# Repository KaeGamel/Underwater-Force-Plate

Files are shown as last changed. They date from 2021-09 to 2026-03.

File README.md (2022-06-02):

# Kaelyn-Gamel
Underwater Force Plate 

Hello all! 

Welcome to the DIY Underwater/Terrestrial Force plate! 

In order to create your own force plate we will be using different platforms and integrating them to gather small forces terrestrially or underwater(can detect .5grams)!

I would start with the files parts and programs needed. I also have attached a word doc that allows you to click on the links for most of the parts to purchase.

Fusion 360 to design the force sensors, Formlab to 3D print.

Matlab to gather data from a NIDAQ that gathers an anolog input from an INA 125P amplifier and Load cell.

EAGLE CAD to generate our circuit (if you want to edit and personalize to your likings)

Most importantly the checklist needed to integrate everything!

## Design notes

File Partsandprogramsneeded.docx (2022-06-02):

Welcome! If you are looking to make your own custom force plate for terrestrial or aquatic locomotion here is a quick setup overview.

Overview:

1) Parts needed
2) Programs needed

Parts needed

Electronics:

Custom circuit boards

INA 125P

Rechargeable 9V batteries

Battery links

Resistors 10- 1,000 ohm

Trim pots 1M-2M

Strain Gauges

Screw Terminals

Multimeter

Heat shrink 3-5mm

Nidaq USB-6002

3D printed parts

STL file from GitHub

Access to Form lab2/3 , Isopropyl, UV cure

Resin tough 2000

Filers and sandpaper

MISC

FP substrate

Aquarium Silicone

Small screwdriver

80-20 T-slot beams

80-20 screws

Programs needed

Part editing and printing

Fusion 360- to edit load cell thicknes

Preform- to print out 3D parts with formlab

EAGLE CAD- edit circuit board

Gather Data

Signal analyzer -in matlab

NIDAQmx tool box – in matlab

National instruments Package manager – National instruments (NI)

Nidaq-mx – using NI package manager

Image processing toolbox- For calibraitons getpts function- Matlab

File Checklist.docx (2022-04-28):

Welcome! If you are looking to make your own custom force plate for terrestrial or aquatic locomotion here is a Checklist and locations of purchase.

Overview:

1) Parts needed
2) Programs needed

Parts needed

Electronics:

Custom circuit boards

INA 125P

Rechargeable 9V batteries

Battery links

Resistors 10- 1,000 ohm

Trim pots 1M-2M

Strain Gauges

Screw Terminals

Multimeter

Heat shrink 3-5mm

Nidaq USB-6002

3D printed parts

STL/f3z file from GitHub

Access to Form lab2/3, Isopropyl, UV cure

Resin tough 2000

Filers and sandpaper

MISC

FP substrate

Aquarium Silicone

Small screwdriver

80-20 T-slot beams

80-20 screws

Programs needed

Part editing and printing

Fusion 360- to edit load cell thicknes

Preform- to print out 3D parts with formlab

EAGLE CAD- edit circuit board

Gather Data

Signal analyzer -in matlab

NIDAQmx tool box – in matlab

National instruments Package manager – National instruments (NI)

Nidaq-mx – using NI package manager

Links for Parts and Programs

Electronics:

Using the eagle files on the github account, you can avoid many headaches by getting PC boards made for you. We ordered from

PCB Prototype & PCB Fabrication Manufacturer - JLCPCB (https://jlcpcb.com/)

Amplifier INA 125P

INA125P Texas Instruments | Integrated Circuits (ICs) | DigiKey (https://www.digikey.com/en/products/detail/texas-instruments/INA125P/254670)

Rechargeable 9V batteries:

Amazon.com: EBL 4 Bay 9V Lithium ion Battery Charger with 4 Packs 600mAh 9V Li-ion Rechargeable Batteries : Electronics (https://www.amazon.com/EBL-Lithium-Battery-Rechargeable-Batteries/dp/B078HP76PG)

Battery links:

Amazon.com: 9 V Battery Clip Connector, I-Type 9 Volt Battery Clip, 9V Battery Buckle Connector Hard Buckle Plastic Housing and Black Red Wires Leads Iength 5.9 inches (I Type Hard Shell 8PCS) : Electronics (https://www.amazon.com/Battery-Connector-I-Type-Plastic-Housing/dp/B07TRKYZCH)

Resistors:

ELEGOO 17 Values 1% Resistor Kit Assortment, 0 Ohm-1M Ohm (Pack of 525) RoHS Compliant: Amazon.com: Industrial & Scientific (https://www.amazon.com/Elegoo-Values-Resistor-Assortment-Compliant/dp/B072BL2VX1)

Trim pots 1M/2M:

Amazon.com: 150 Pcs 15 Value 100 ohm- 2M ohm Trimpot Variable Resistor 6mm Potentiometer Assortment Kit : Industrial & Scientific (https://www.amazon.com/Trimpot-Variable-Resistor-Potentiometer-Assortment/dp/B071WW6VN8)

Strain gauges 120 or 350 ohm:

https://www.omega.com/en-us/force-strain-measurement/strain-gauges/linear-strain-gauges/kfh-linear/p/KFH-3-350-C1-11L1M2R

Screw Terminals:

KeeYees 60pcs 5mm Pitch 2 Pin & 3 Pin PCB Mount Screw Terminal Block Connector for Arduino (50 x 2 Pin, 10 x 3 Pin): Amazon.com: Industrial & Scientific (https://www.amazon.com/KeeYees-60pcs-Terminal-Connector-Arduino/dp/B07H5G7GC6)

Multimeter:

AstroAI Multimeter 2000 Counts Digital Multimeter with DC AC Voltmeter and Ohm Volt Amp Tester ; Measures Voltage, Current, Resistance; Tests Live Wire, Continuity - - Amazon.com (https://www.amazon.com/AstroAI-Digital-Multimeter-Voltage-Tester/dp/B01ISAMUA6)

Heat shrink

uxcell Wire Wrap Sleeve 3 mm Dia 30 mm Long Heat Shrink Tubing 240Pcs Black: Amazon.com: Industrial & Scientific (https://www.amazon.com/Uxcell-Sleeve-Shrink-Tubing-240Pcs/dp/B01461R89O)

Nidaq USB 6002→ There are other NI systems that can be used and purchased on ebay. The system just needs 4 terminal inputs with Individual ground. This is an Analog reader

USB-6002 - NI (https://www.ni.com/en-us/support/model.usb-6002.html)

3D prints

Form lab:

Form 3 Package (formlabs.com) (https://formlabs.com/store/form-3-basic-package-without-service/)

Resin Tough 2000:

Resin Family: Tough and Durable (formlabs.com) (https://formlabs.com/materials/tough-durable/)

Fine filers

https://www.amazon.com/Hardened-Strength-Warding-Triangular-Half-Round/dp/B07WDCBJ1G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

MISC

FP substrate:

Amazon.com : NVAAV 2pcs Grid Divider Tray for Aquarium, Fish Tank Bottom Isolation, Egg Crate Tank Divider Filter Tray for Mixed Breeding : Pet Supplies (https://www.amazon.com/dp/B08V8NQ1K9)

Silicone

https://www.amazon.com/Aqueon-100165003-Silicone-3-oz/dp/B0002ASD2K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

small screw drivers

https://www.amazon.com/Screwdriver-Different-Flathead-Screwdrivers-Precision/dp/B08B87RQJ9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

80-20 construction parts are easiest for the force plate creation but if funding is unavailable other alternatives are available.

80/20 T-slot Aluminum Building System (8020.net)

Programs:

Part editing and printing

Fusion 360

Download Fusion 360 for free | Fusion 360 | Autodesk (https://www.autodesk.com/campaigns/fusion-360/dream-to-done)

Preform

Installing PreForm software (formlabs.com) (https://support.formlabs.com/s/article/Install-PreForm-Software?language=en_US)

EAGLE CAD

Download EAGLE | Free Download | Autodesk (https://www.autodesk.com/products/eagle/free-download)

Gathering data

Signal analyzer Matlab: Using Signal Analyzer App - MATLAB & Simulink (mathworks.com) (https://www.mathworks.com/help/signal/ug/using-signal-analyzer-app.html)

NIDAQmx Toolbox Matlab NI-DAQmx Support from Data Acquisition Toolbox - Hardware Support - MATLAB & Simulink (mathworks.com) (https://www.mathworks.com/hardware-support/nidaqmx.html)

National instruments Package manager: https://www.ni.com/en-us/support/downloads/software-products/download.package-manager.html

Nidaq-mx – using NI package manager: NI-DAQmx Download - NI (https://www.ni.com/en-us/support/downloads/drivers/download.ni-daqmx.html)

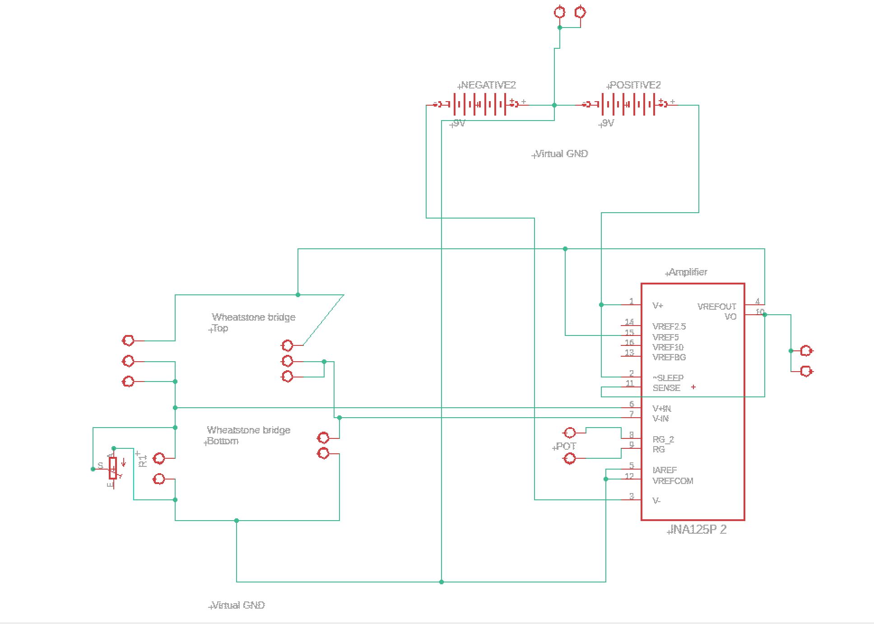
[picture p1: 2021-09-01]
EAGLE files/Raw Circuit design.JPG

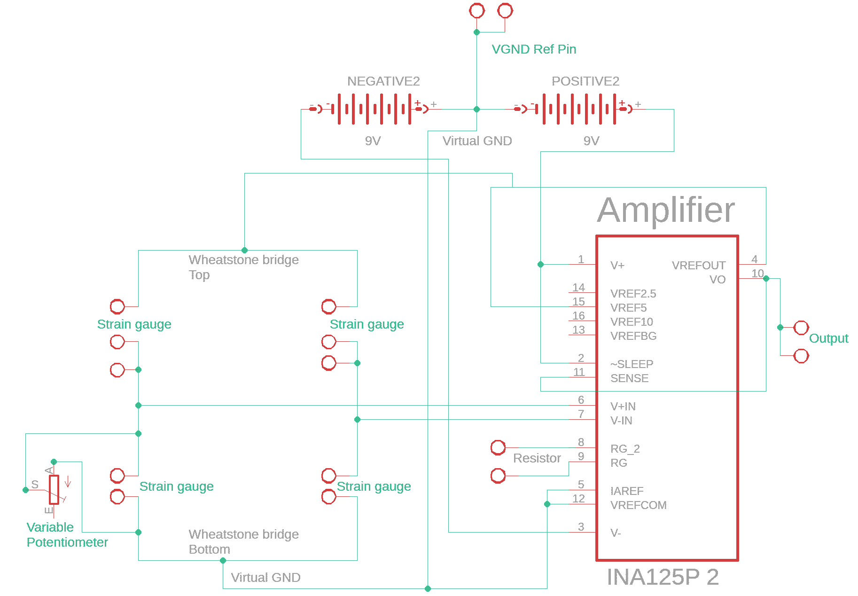
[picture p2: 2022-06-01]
Circuit board.png

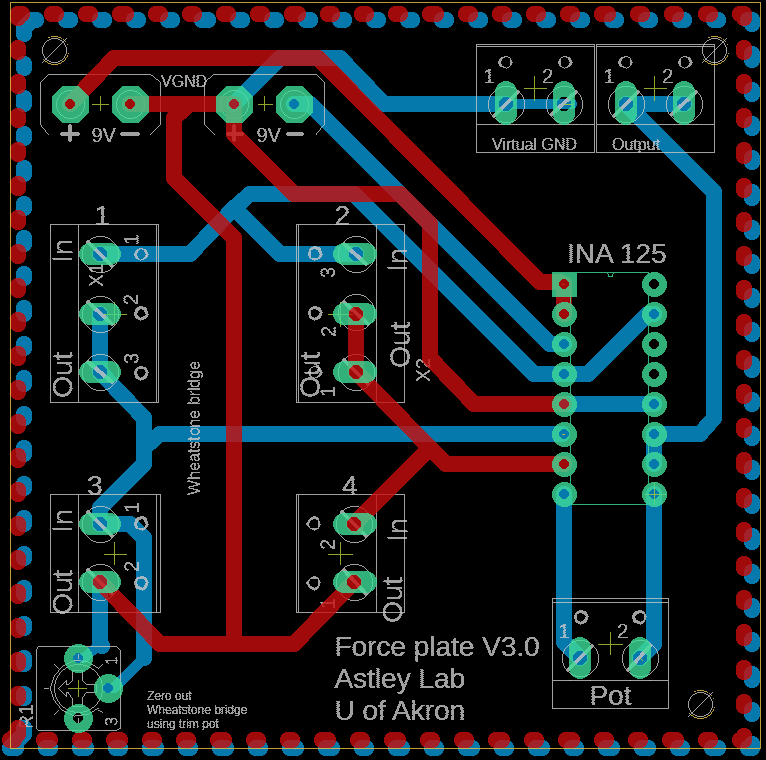
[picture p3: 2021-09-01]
EAGLE files/Image of Circuit.png

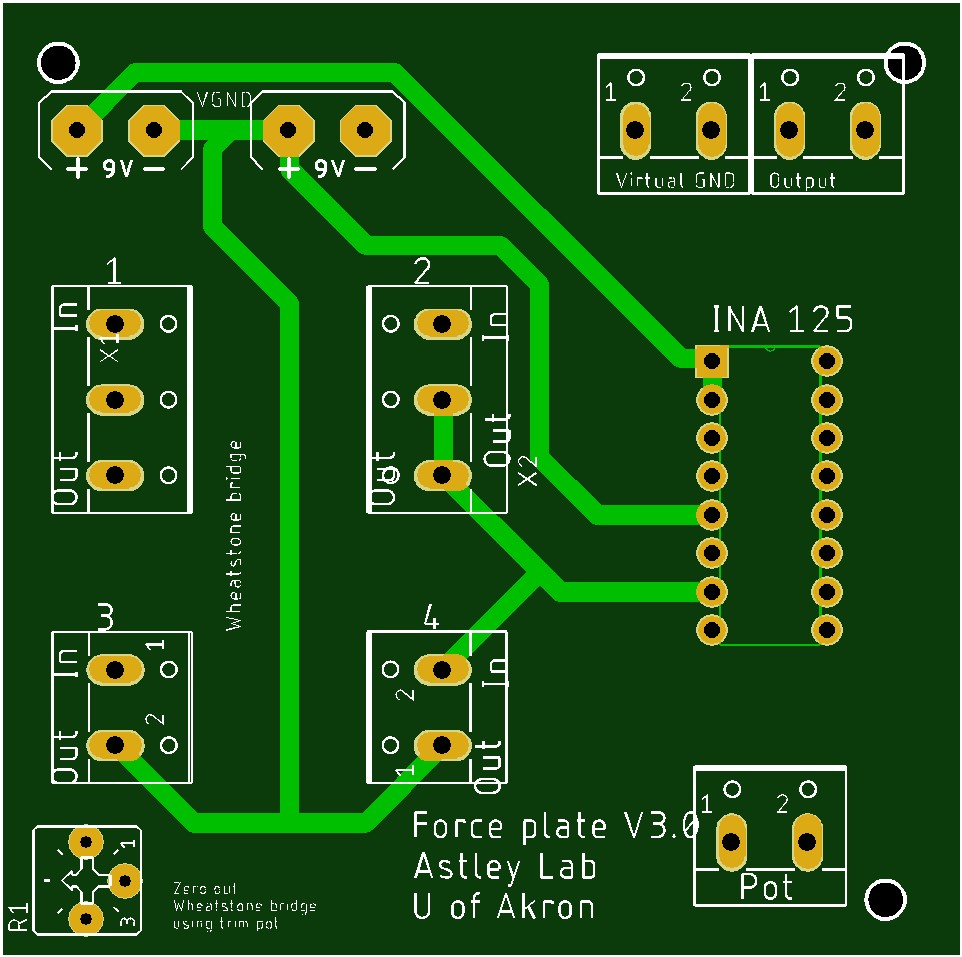
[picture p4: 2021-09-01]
EAGLE files/Image of Circuit board.jpg

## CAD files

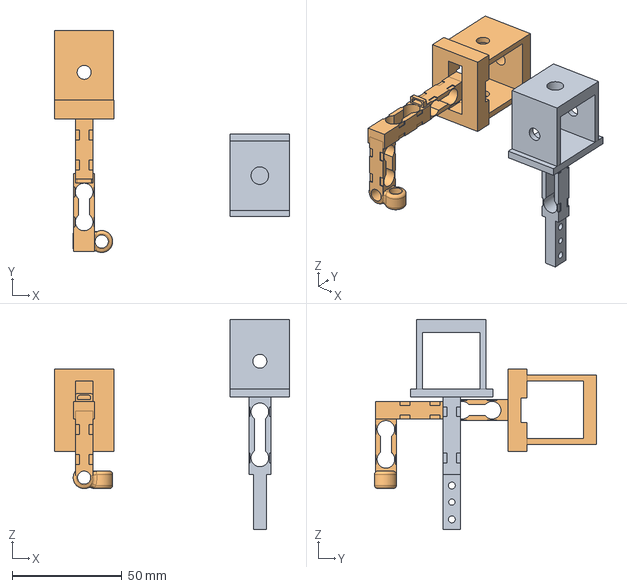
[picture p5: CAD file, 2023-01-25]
single load cell and triaxis load cell.step
107.0 x 101.1 x 95.7 mm
3 axis (2)
3 axis (2)_1

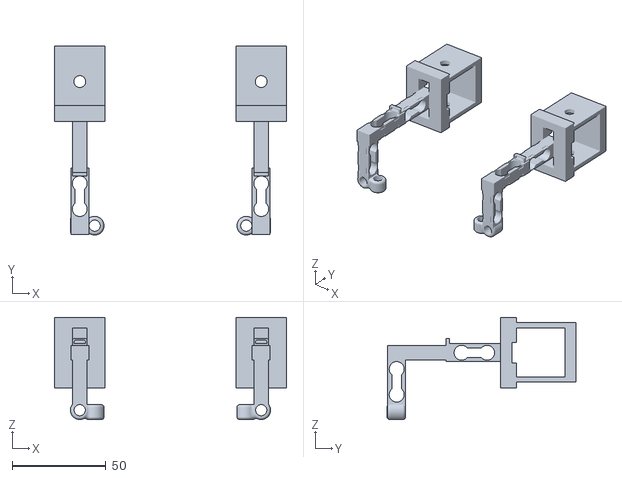
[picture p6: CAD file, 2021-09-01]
Corner 1 and 2 8020 stl file.stl
124.0 x 101.1 x 54.6

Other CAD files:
Corner 1 and 2 8020 Sept 1.f3z

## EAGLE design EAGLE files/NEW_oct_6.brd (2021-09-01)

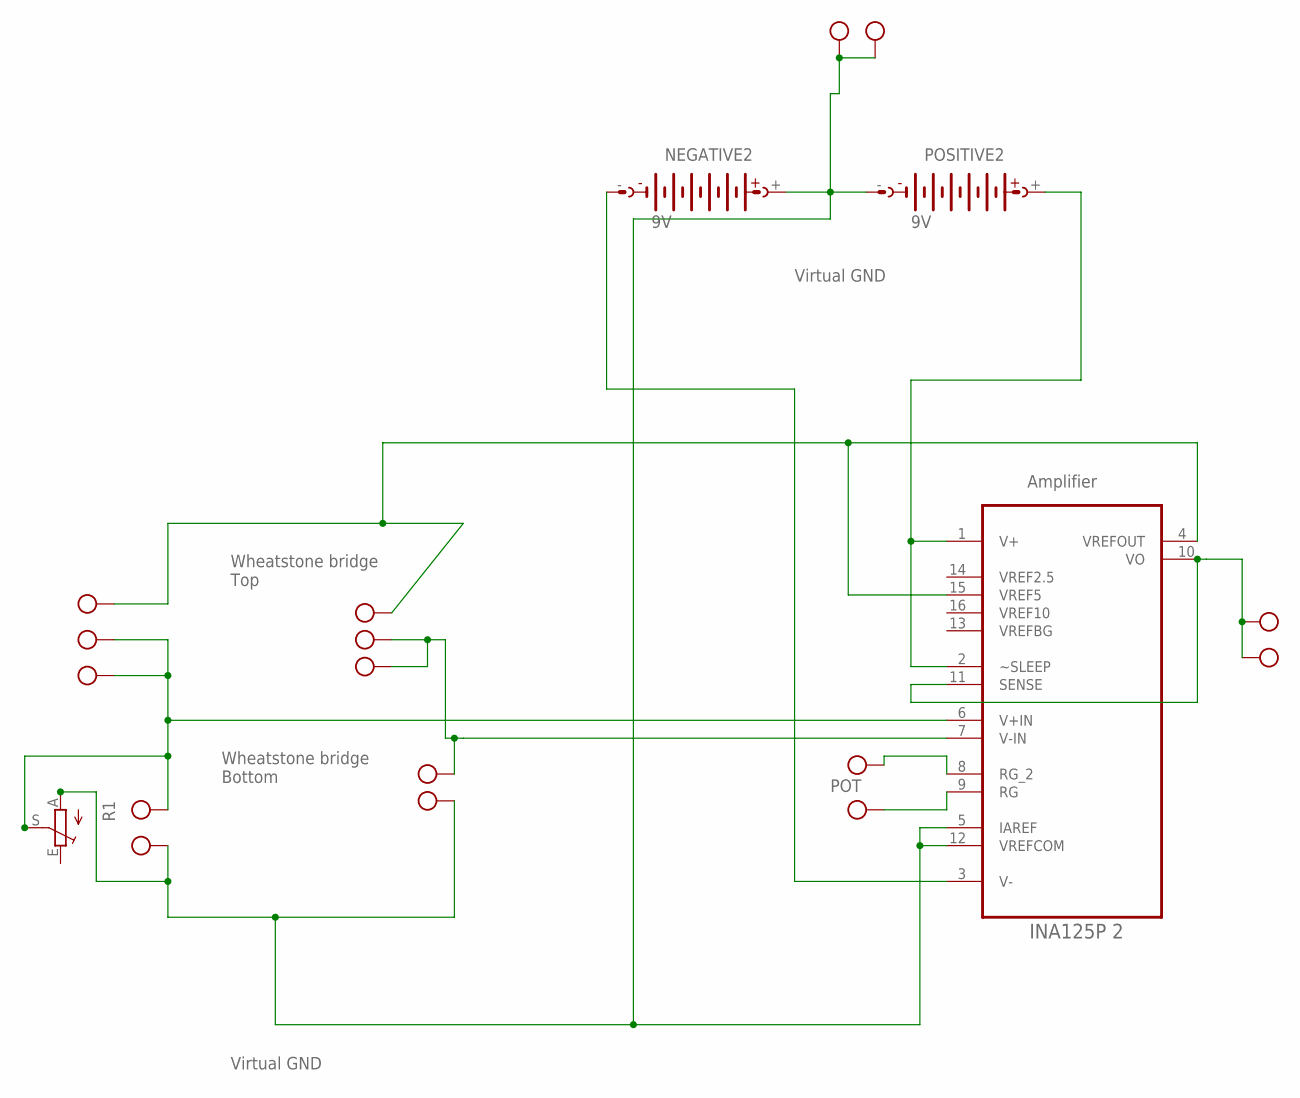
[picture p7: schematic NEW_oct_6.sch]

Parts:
FOURTH2, FOURTH5, FOURTH8: W237-102
NEGATIVE2: AB9V
POSITIVE2: AB9V
POT2: W237-102
R1: TRIM_EU-CT6; CT6
SECOND2: W237-102
U3: INA125P 2; DIP254P762X508-16
X1, X2: W237-103

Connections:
unnamed: R1.S, SECOND2.1, U3.6 (V+IN), X1.2, X1.3
unnamed: FOURTH2.2, U3.7 (V-IN), X2.1, X2.2
unnamed: U3.4 (VREFOUT), U3.15 (VREF5), X1.1, X2.3
unnamed: POSITIVE2.+, U3.1 (V+), U3.2 (~SLEEP)
unnamed: NEGATIVE2.-, U3.3 (V-)
unnamed: POT2.2, U3.9 (RG)
unnamed: POT2.1, U3.8 (RG_2)
unnamed: FOURTH5.1, FOURTH5.2, U3.10 (VO), U3.11 (SENSE)
unnamed: FOURTH2.1, FOURTH8.1, FOURTH8.2, NEGATIVE2.+, POSITIVE2.-, R1.A, SECOND2.2, U3.5 (IAREF), U3.12 (VREFCOM)
VREF2.5: U3.14 (VREF2.5)
VREF10: U3.16 (VREF10)
VREFBG: U3.13 (VREFBG)

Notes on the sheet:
Virtual GND
Wheatstone bridge Top
Wheatstone bridge Bottom
POT
Amplifier

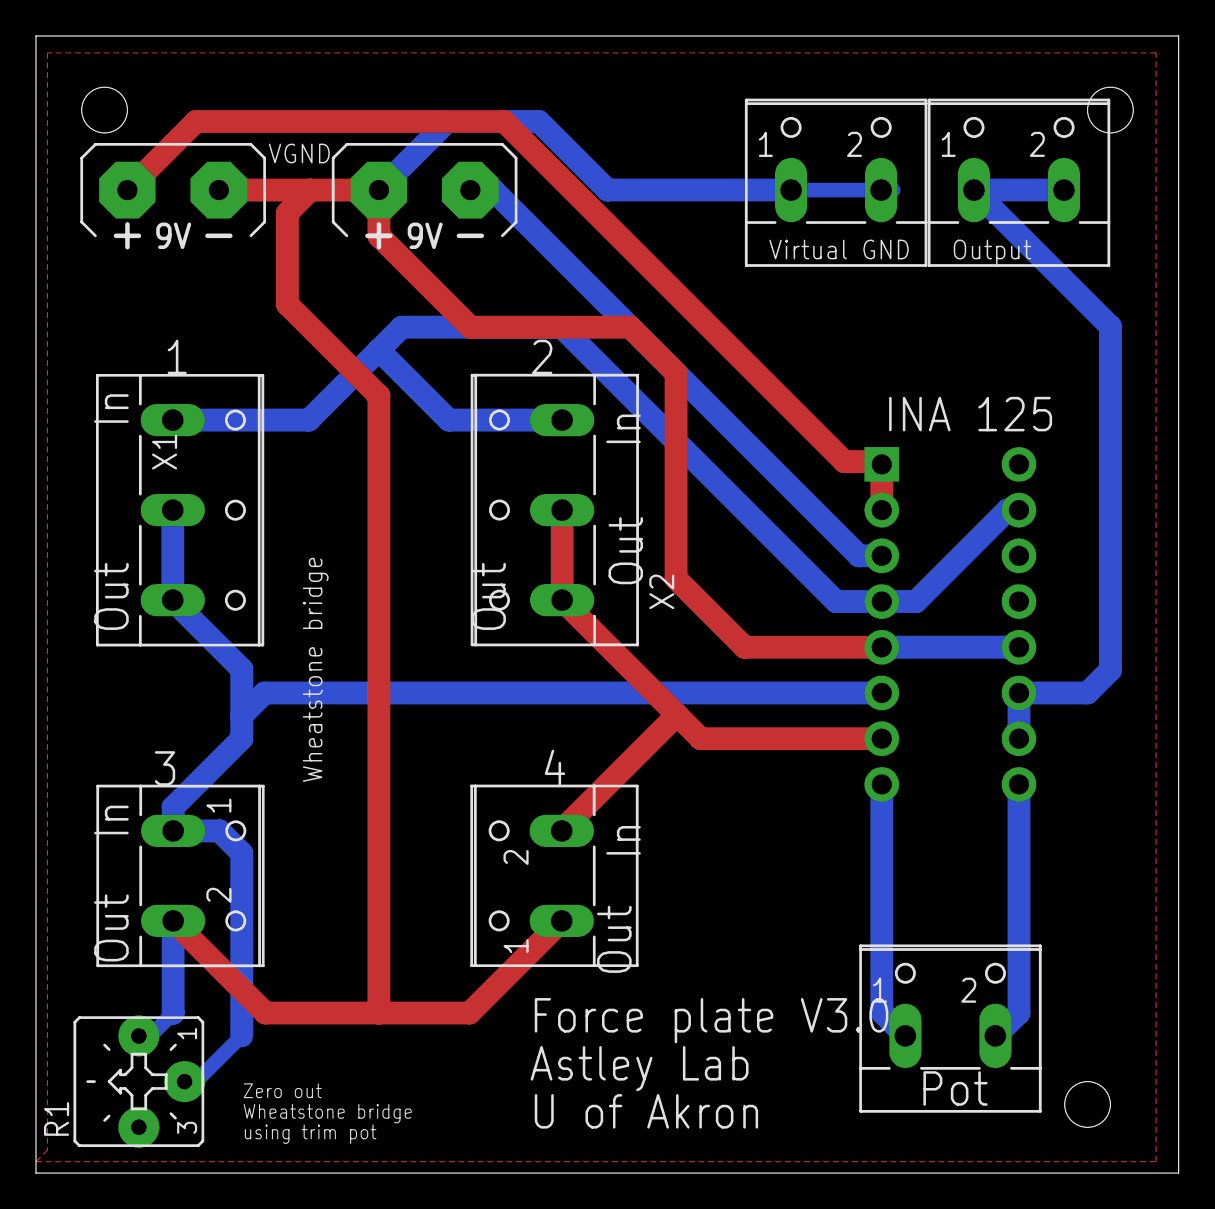
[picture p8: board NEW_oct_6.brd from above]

Board: 2 copper layers, 63.5 x 63.2 mm, 11 parts (0 on the bottom side), 9 nets.

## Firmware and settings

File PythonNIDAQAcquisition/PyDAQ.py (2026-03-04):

import numpy as np
import nidaqmx
from nidaqmx import constants
from keyboard import is_pressed

DEVICE = "Dev2"
ANALOG_CHANNELS = [f"{DEVICE}/ai0",  # list of analog channels to listen to
                   f"{DEVICE}/ai1",
                   f"{DEVICE}/ai2",
                   f"{DEVICE}/ai3"]
CHUNK_DURATION = 1  # number of seconds each chunk should last
SAMPLE_RATE = 4000  # number of samples to be recorded per chunk
DURATION = 100  # overarching duration of recording, in seconds

# Calculate chunk size and number of chunks
chunk_size = SAMPLE_RATE * CHUNK_DURATION
total_chunks = DURATION // CHUNK_DURATION
print(f"Chunk size: {chunk_size} | Total chunks: {total_chunks}")

# Data acquisition and storing in memory
data_in_memory = {channel: [] for channel in ANALOG_CHANNELS}  # start with a set of empty lists
print(f"Please press SPACEBAR to begin reading from {DEVICE}...")
while True:
    if is_pressed('space'):  # if SPACEBAR is pressed...
        break  # break out of the loop

try:
    with nidaqmx.Task() as task:
        for channel in data_in_memory.keys():  # add voltage channels to active task
            task.ai_channels.add_ai_voltage_chan(channel, terminal_config=constants.TerminalConfiguration.RSE)

        task.timing.cfg_samp_clk_timing(rate=SAMPLE_RATE,  # configure sample rate and mode of active task
                                        sample_mode=constants.AcquisitionType.CONTINUOUS)

        # Read data in chunks and store in memory
        for _ in range(total_chunks):
            chunk_data = task.read(number_of_samples_per_channel=chunk_size)
            print(f"Reading chunk of length {len(chunk_data[0])}")
            for i, channel in enumerate(data_in_memory.keys()):
                data_in_memory[channel].append(chunk_data[i])  # fill each list in the set with data

        task.stop()
        print(f"\nFinished reading from {DEVICE}.")
finally:
    if task:
        task.close()
        print("Task complete.")

# Conversion of lists to numpy arrays for processing
for channel in data_in_memory:
    print(f"Pre-concatenation length for {channel}: {sum(len(chunk) for chunk in data_in_memory[channel])}")
    data_in_memory[channel] = np.concatenate(data_in_memory[channel])
    print(f"Post-concatenation length for {channel}: {len(data_in_memory[channel])}")

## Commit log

2021-07-15 Create Interacting with load Sensors and NIDAQ
2021-09-01 Corner 1 and corner 2 Fusion 360 file
    [Corner 1 and 2 8020 Sept 1.f3z]
2021-09-01 Stl File
    [Corner 1 and 2 8020 stl file.stl]
2021-09-01 Circuit design
    [NEW_oct_6.brd, NEW_oct_6.sch]
2021-10-21 CD added code
    Added new matlab calibration code for easier clicking :)
2021-10-26 Added Calibration Matrix calculator for Matlab
2022-01-18 Added code to sync kinematics data
2022-05-03 Add kinematics variables to force code
2022-05-25 Added plotting for 3+ y-axis
2022-06-01 Circuit Board Schematic
    INA 125P Schematic to amplify a custom Load cell using strain gauges in a Wheatstone bridge configuration
2022-06-02 Update create calibration matrice.py
    ### No words allowed in the Excel file:
    ## these numbers come from running the data file in matlab adding and removing weight
    ## THEN running calibration code clicking the get pts and then extracting the number spit out for each specific weight
    ## here is an example that will spit out a calibration matrix
    ## Vert Voltage, Fore-aft Voltage, Lateral voltage, Actual weight placed Vertically, Actual weight placed foreaft, Actual weight placed lateral
    ### EX. .508 , .02, .03, 5 grams, 0 grams, 0 grams
    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
2023-01-25 STEP File 3D load cells
    [single load cell and triaxis load cell.step]
2023-05-17 Add files via upload
    Added a MATLAB version of the code to find a calibration matrix
2026-02-24 Gerber Files
    Gerber Files for Newer Circuit Printing (e.g. JLCPCB)
2026-09-02 Delete EAGLE files/GerberFiles.zip
    Discovered fatal flaw in INA125p footprint that arose from importing into Autodesk Fusion 360 to make Gerber.
